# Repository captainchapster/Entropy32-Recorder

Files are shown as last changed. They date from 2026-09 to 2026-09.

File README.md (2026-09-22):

# Entropy32 Recorder

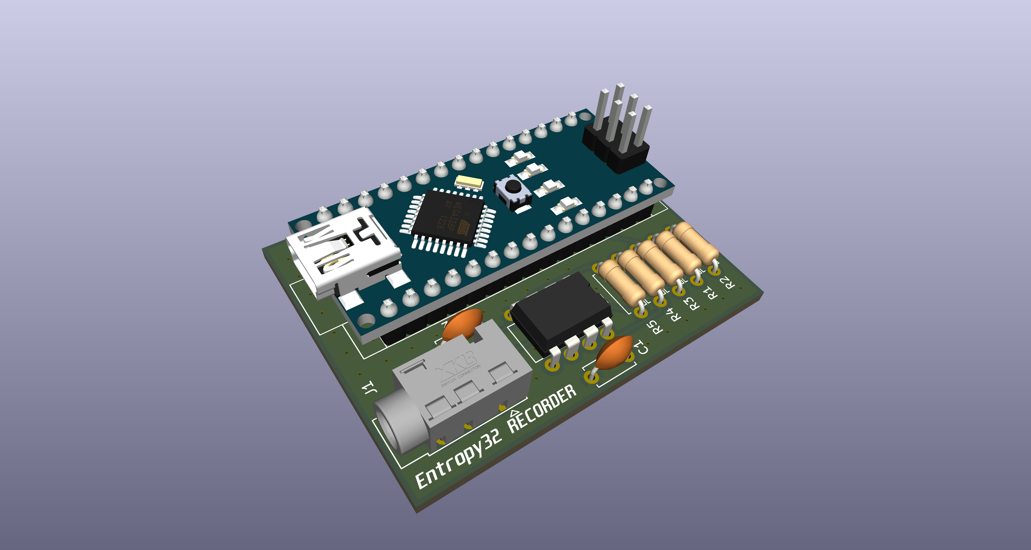
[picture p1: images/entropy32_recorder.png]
Assembled PCB


Firmware, hardware, and tooling for the Entropy32 Recorder — a standalone
Geiger-counter-based board, built around an ATmega328P (Arduino Nano form
factor), for recording raw entropy source data.

This is a **separate board from Entropy32 / Entropy32 Plus**, not a mode or
alternate firmware of it. It does not generate seeds or any conditioned
output. Its only job is to capture raw, unconditioned edge timing data from
the entropy source (Geiger tube + LM393 comparator) so it can be run through
statistical test suites (e.g. NIST STS) to validate the quality of the
entropy source itself, before that source is trusted for use in Entropy32
Plus's seed generation.

## Repository layout

- **`entropy32_evidence_protocol.md`** — the SP 800-90B reproducible
  evidence protocol these tools implement: capture requirements, the
  raw/derived evidence package layout, exact firmware reconstruction
  semantics, and the pinned NIST toolchain invocation.
- **`entropy32_recorder.ino`** — the recorder's firmware. It timestamps
  every rising edge on D2 (post-LM393 comparator output) and streams
  `edge_index,timestamp_us` CSV rows over serial. It does no filtering,
  interval pairing, or SHA-256 conditioning by design — it's for capturing
  raw edge timing data only, unmodified, for statistical testing.
- **`tools/capture_serial_to_csv.py`** — reads the serial stream produced by
  the sketch above and writes it to a CSV file matching the evidence
  protocol's `raw/raw_edges.csv` shape (`edge_index`, `raw_timer_ticks`,
  `monotonic_timestamp_us`). `raw_timer_ticks` is the board's `micros()`
  reading exactly as received (wraps every ~71.58 min);
  `monotonic_timestamp_us` is that value unwrapped into an ever-increasing
  64-bit microsecond count, reconstructed on the host (via
  `tools/edge_timing.py`) so the firmware/ISR stays minimal. Every row is
  flushed and fsynced to disk as soon as it's written — negligible cost at
  this source's event rate, and each edge is an irreplaceable physical
  event, so nothing is ever buffered short of an actual power loss. One
  capture is one continuous, uninterrupted run from edge 0 — per the
  evidence protocol, there is no resume; the tool refuses to run at all
  if `--out` already has data, and an interrupted capture must be
  restarted under a new `--out` rather than continued. On a fully
  complete run, also writes a `capture_status.json` sibling (e.g.
  `raw_edges.status.json`) recording edge count, start/end UTC
  timestamps, and the zero overrun/drop counts implied by reaching that
  point at all — this feeds `tools/package_evidence.py` and the
  protocol's `capture_status.json` (§4). Requires `pyserial`.
- **`tools/edge_timing.py`** — the timer-wrap-unwrapping math used by the
  capture tool, in its own module mainly so it can be tested in isolation.
- **`tools/check_edges.py`** — pre-flight sanity check for a captured CSV:
  confirms `edge_index`/`monotonic_timestamp_us` are well-formed, and
  compares the inter-arrival distribution against a Poisson expectation to
  flag comparator bounce/chatter. Run this before feeding a capture into
  NIST STS / SP 800-90B tooling:
  `python tools/check_edges.py tools/raw_edges.csv`.
- **`tools/derive_evidence.py`** — reconstructs Entropy32's actual
  bit-extraction (200us reject filter, non-overlapping interval pairing,
  second-longer=1/second-shorter=0, ties discarded) per
  `entropy32_evidence_protocol.md` §5,
  producing the protocol's `derived/` package — `all_intervals_us.csv`,
  `firmware_accepted_intervals_us.csv`, `comparison_bits.bin`,
  `derivation_report.json`.
  `python tools/derive_evidence.py tools/raw_edges.csv --out-dir tools/derived --source-dir ../entropy32_plus`.
  `comparison_bits.bin` is ready for `ea_non_iid -i -v comparison_bits.bin 1`
  (bits_per_symbol=1, per the protocol's §8 — not a byte-per-symbol
  truncation). `--source-dir` (optional but recommended) points at a local
  checkout of the firmware these constants are claimed to match, and
  auto-fills `derivation_report.json`'s `source_repo`/`source_commit`/
  `entropy32_firmware_blob_sha` from its git metadata and `.ino` hash —
  left `"unknown"` rather than guessed if omitted.
- **`tools/package_evidence.py`** — assembles the protocol's immutable
  evidence directory (§4) from a capture, a `derive_evidence.py` run, and
  a separately-run `ea_non_iid` pass: copies `raw/` and `derived/` in,
  records the exact NIST command/toolchain/exit status under `nist/`,
  writes `capture_status.json` and a `manifest.json` (fields it can't
  know — hardware, physical source, environment — are left `null` and
  listed on stdout for manual completion), and computes a `SHA256SUMS`
  covering every file in the package.
- **`KiCad/`** — PCB design (schematic, layout, 3D models, and
  fabrication/production outputs for the Entropy32 Recorder board).

## Hardware

Assembled PCB

The board pairs a Geiger tube's LM393 comparator output with an ATmega328P
(D2, using the board's existing pull-down for bias). Design files are in
[`KiCad/`](KiCad/), including BOM, designators, netlist, and pick-and-place
files under `KiCad/production/`.

## Usage

All commands below assume you're in the repo root (`entropy32_recorder/`)
and refer to files under `tools/` explicitly — that avoids the most common
mistake, running a later step from the wrong directory against a bare
filename that only exists one level down.

1. Flash `entropy32_recorder.ino` to the board.
2. Install the one Python dependency, then run the capture tool:

   ```
   pip install pyserial
   python tools/capture_serial_to_csv.py --port COM5 --count 2000 --out tools/raw_edges.csv
   ```

   (`--port` is a COM port like `COM5` on Windows, or a device path like
   `/dev/ttyUSB0` on Linux.) This writes `tools/raw_edges.csv` and, once
   the run completes fully, a `tools/raw_edges.status.json` sibling.
3. If the board reports `OVERRUN_DETECTED`, or the capture stops for any
   other reason (crash, USB drop, closing the terminal), that run is
   invalid per the evidence protocol — one capture is one continuous,
   uninterrupted run from edge 0. Start over under a new `--out`; there
   is no resume. Don't reuse `tools/raw_edges.csv` as the target for a new
   capture once an earlier one has already been packaged (step 7) — that
   overwrites the file the earlier package's hashes were computed from.
4. Sanity-check the result before running heavier statistical tests:

   ```
   python tools/check_edges.py tools/raw_edges.csv
   ```

5. Reconstruct Entropy32's actual bit stream:

   ```
   python tools/derive_evidence.py tools/raw_edges.csv --out-dir tools/derived --source-dir ../entropy32_plus
   ```

   This writes `tools/derived/comparison_bits.bin` (and the other
   `derived/` files) ready for the NIST tool below.
6. Run the NIST non-IID test suite against `comparison_bits.bin`.

   `ea_non_iid` is a Linux build — on Windows you'll need
   [WSL](https://learn.microsoft.com/en-us/windows/wsl/install)
   (`wsl --install`, one-time). Build it once, from inside WSL (or any
   Linux/macOS shell):

   ```bash
   sudo apt update && sudo apt install -y build-essential libbz2-dev
   git clone https://github.com/usnistgov/SP800-90B_EntropyAssessment.git
   cd SP800-90B_EntropyAssessment
   git checkout 68ed165fd7a3eeef26b87a546ba23f338e82a3f3  # pinned v1.1.8, see protocol §8
   make
   cd selftest && ./selftest && cd ..
   make non_iid
   ```

   The binaries land in `cpp/`, not the repo root — run `ea_non_iid` from
   there. From WSL, your Windows checkout is under `/mnt/<drive letter>/...`
   (e.g. `/mnt/d/Programming/entropy32_recorder`). Run it and save its
   stdout/stderr/exit status verbatim — the next step needs all three:

   ```bash
   cd SP800-90B_EntropyAssessment/cpp
   REPO=/mnt/d/Programming/entropy32_recorder
   ./ea_non_iid -i -v "$REPO/tools/derived/comparison_bits.bin" 1 \
     > "$REPO/tools/nist_stdout.txt" 2> "$REPO/tools/nist_stderr.txt"
   echo $? > "$REPO/tools/nist_exit_status.txt"
   g++ --version | head -1   # note this down for --nist-compiler-version below
   ```

7. Assemble the immutable evidence package:

   ```
   python tools/package_evidence.py \
     --raw tools/raw_edges.csv --derived-dir tools/derived --capture-id <your-id> \
     --nist-command "./ea_non_iid -i -v comparison_bits.bin 1" \
     --nist-stdout tools/nist_stdout.txt --nist-stderr tools/nist_stderr.txt \
     --nist-exit-status 0 --nist-compiler-version "<g++ --version output from step 6>"
   ```

   `--capture-status` doesn't need to be passed explicitly — it's
   auto-detected from `tools/raw_edges.status.json`. This writes
   `entropy32_sp80090b_<your-id>/` in the repo root; that directory,
   not the loose `tools/raw_edges.csv` / `tools/derived/` / `tools/nist_*`
   files that fed it, is what should get committed as the evidence record.

   Fill in whichever `manifest.json` fields it lists as left `null`
   (hardware revision, physical source, environment) by hand — see
   `entropy32_evidence_protocol.md` for what the full package and
   restart testing require beyond this.

## Known limitations / best practices for a full campaign

- **Sample size**: a few thousand edges (a few hours at typical background
  rates) is only enough for a pipeline smoke test. SP 800-90B-style
  min-entropy estimation wants **>= 1,000,000 samples** before the result
  is meaningful — plan campaign length accordingly (at the ~16 CPM
  background rate seen in the pilot run, 1M edges is roughly 6 weeks of
  continuous capture).
- **Timestamp resolution**: `micros()` on the ATmega328P (16MHz, Timer0
  prescaler 64) only increments in steps of 4us. That's negligible at the
  observed ~3.7s mean inter-arrival time (1 part in ~10^6), so it isn't a
  concern at current event rates. If a future hardware revision moves the
  comparator output to the Timer1 input-capture pin (`ICP1` / D8 on a
  Nano) instead of D2, the ISR could latch `TCNT1` directly for
  microsecond-or-better hardware-timestamped edges with no software ISR
  jitter — worth considering for a higher-throughput source, but out of
  scope for the current board (D2 is fixed on the fabricated PCB).
- **Comparator bounce**: `check_edges.py` compares the inter-arrival
  distribution against the Poisson process a radioactive source should
  produce; a pileup of anomalously short gaps indicates LM393 output
  chatter rather than genuine independent events. No bounce was observed
  in the pilot 2000-edge run.

## License

- Firmware and software (`entropy32_recorder.ino`, `tools/`): [MIT](LICENSE)
- Hardware (`KiCad/`): [CERN-OHL-S v2](LICENSE-HARDWARE)

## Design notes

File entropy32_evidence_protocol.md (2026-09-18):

# Entropy32 Plus · SP 800-90B Reproducible Evidence Protocol v0.1

**Status:** evidence protocol, not certification.
**Drafted by:** Cosmographer / BHRIGU

This protocol is written to apply to any build of the Entropy32 Plus
firmware. Pin the specific repository, commit, and firmware blob hash you
are evaluating in your own manifest (§10) rather than in this document.

Entropy32 currently measures Geiger pulse inter-arrival time using D2, rejects intervals below `200 µs`, consumes accepted intervals in non-overlapping pairs, discards ties, emits `1` when the second interval is longer and `0` when shorter, and only then runs health tests / fills the 512-bit pool. Entropy32 Plus's own README correctly notes that runtime health tests are not full entropy validation, and that a long raw inter-arrival dataset still needs SP 800-90B non-IID assessment.

## 1. Evidence boundary

The acquisition point is:

```text
PHYSICAL SOURCE
    ↓
Geiger detector pulse
    ↓
LM393 comparator
    ↓
D2 rising edge
    ↓
[CAPTURE HERE]
    ↓
200 µs filter
    ↓
non-overlapping interval pairing
    ↓
comparison bit
    ↓
RCT / APT
    ↓
512-bit pool
    ↓
SHA-256
```

**Every D2 rising edge is recorded before any filtering, pairing, health test, pool logic or SHA-256.**

For this protocol:

```text
RAW EVIDENCE
= direct D2 edge observations

DERIVED EVIDENCE
= intervals, accepted intervals,
  comparison bits and statistical results
  reconstructed from those observations
```

One terminology note matters: SP 800-90B calls the digitized output of the defined noise source its “raw data.” Here we deliberately preserve an even earlier observational authority—the D2 edge timestamps—so that different candidate digitized-sample definitions can be reconstructed without recollecting the experiment. NIST explicitly expects access to digitized noise-source data for validation and external testing. ([NIST Publications](https://nvlpubs.nist.gov/nistpubs/specialpublications/nist.sp.800-90b.pdf "Recommendation for the Entropy Sources Used for Random Bit Generation"))

---

## 2. Recorder requirements

The recorder must timestamp edges itself. **PC receive time must never be used as the entropy timestamp.**

Required properties:

| Property | Requirement |
| --- | --- |
| Input | rising edge on the same post-LM393 signal used as Entropy32 D2 |
| Timestamp source | free-running hardware timer |
| Resolution | **≤ 1 µs preferred; never worse than the Entropy32 timing resolution** |
| Clock | oscillator source and nominal frequency recorded |
| Monotonicity | recorder maintains an unambiguous monotonically increasing timestamp across timer wraps |
| Edge index | 64-bit monotonically increasing counter, incremented for every captured edge |
| ISR | only timestamp/store; no printing, formatting or blocking I/O |
| Buffer | ring/DMA buffer; overflow counter mandatory |
| Transport | foreground transfer to PC |
| Drop detection | sequence gaps or buffer overrun invalidate the capture |
| Capture end | sample-count based, not time based |

Current Entropy32 uses `micros()` on a 16 MHz ATmega328P. The standard Arduino AVR implementation derives `micros()` from Timer0 with a 64-clock prescaler; at 16 MHz its returned values advance in 4 µs units. ([GitHub](https://github.com/arduino/ArduinoCore-avr/blob/master/cores/arduino/wiring.c?utm_source=chatgpt.com "ArduinoCore-avr/cores/arduino/wiring.c at master · arduino/ArduinoCore-avr · GitHub"))

Therefore the recorder should preserve higher-resolution physical timestamps but also record enough timing/toolchain metadata to reproduce the deployed Entropy32 timing semantics. The manifest must state the actual Arduino AVR core/toolchain used by the device; the firmware repository alone does not pin that dependency.

### Overflow handling

Do **not** allow a wrapped 32-bit timestamp to become ambiguous.

Recommended stored edge record:

```text
edge_index
raw_timer_ticks
monotonic_timestamp_us
```

`monotonic_timestamp_us` must remain increasing for the whole run. If the underlying hardware timer wraps, the recorder must extend it before writing the evidence record.

### Dropped-event criterion

A run is valid only if:

```text
first_edge_index = 0
every next edge_index = previous + 1
buffer_overrun_count = 0
transport_drop_count = 0
records_received = recorder_records_sent
```

Any violation:

```text
CAPTURE_INVALID
```

Do not patch the file or interpolate missing events.

---

## 3. Minimum acquisition length

NIST requires at least **1,000,000 sequential noise-source samples** for the sequential dataset; if multiple consecutive segments are concatenated, each segment must contain at least 1,000 samples. ([NIST Publications](https://nvlpubs.nist.gov/nistpubs/specialpublications/nist.sp.800-90b.pdf "Recommendation for the Entropy Sources Used for Random Bit Generation"))

For this evidence package, use a stricter practical stop gate:

```text
UNFILTERED_INTERARRIVAL_SAMPLES >= 1,000,000

AND

COMPARISON_BITS >= 1,000,000
```

That ensures there is enough evidence to inspect the physical timing observations **and** a full one-million-sample binary dataset corresponding to the stream actually entering Entropy32's health-test/pool path.

Because each comparison bit consumes two accepted intervals and ties emit no bit, the recorder must continue until the second condition is reached rather than assuming a fixed number of pulses.

The capture duration therefore depends on observed count rate. It is not defined by isotope, CPM estimate or wall-clock duration.

---

## 4. Immutable package

The final evidence directory is:

```text
entropy32_sp80090b_<capture-id>/

  manifest.json
  capture_status.json
  SHA256SUMS

  raw/
    raw_edges.csv

  derived/
    all_intervals_us.csv
    firmware_accepted_intervals_us.csv
    comparison_bits.bin
    derivation_report.json

  nist/
    TOOLCHAIN.txt
    comparison_non_iid.command.txt
    comparison_non_iid.stdout.txt
    comparison_non_iid.stderr.txt
```

### `raw/raw_edges.csv`

One record per physical D2 rising edge:

```text
edge_index,raw_timer_ticks,monotonic_timestamp_us
0,...
1,...
2,...
...
```

This file is the primary observational authority.

Once closed:

1. do not edit, sort, normalize or re-export it;
2. calculate SHA-256 immediately;
3. include that digest in `SHA256SUMS` and `manifest.json`.

---

## 5. Exact firmware reconstruction

Starting from `raw_edges.csv`, first derive every consecutive physical inter-arrival value:

```text
all_interval[n] =
edge_timestamp[n] - edge_timestamp[n-1]
```

Do **not** apply modulo, low-byte extraction, bucketing or truncation.

Then reconstruct current Entropy32 semantics.

Current firmware does something subtle and important: an interval below `200 µs` is rejected **without updating** **`lastPulseMicros`**. The next interval is therefore measured from the last accepted edge, not from the rejected edge.

Equivalent reconstruction:

```text
last_accepted_edge = NONE
have_first_interval = false

for each raw D2 edge in original order:

    if first edge:
        last_accepted_edge = edge
        continue

    interval =
        edge.time - last_accepted_edge.time

    if interval < 200 µs:
        reject
        DO NOT update last_accepted_edge
        continue

    accepted interval

    if have_first_interval == false:
        first_interval = interval
        have_first_interval = true

    else:
        second_interval = interval

        if second_interval > first_interval:
            emit comparison bit 1

        if second_interval < first_interval:
            emit comparison bit 0

        if second_interval == first_interval:
            emit no bit

        have_first_interval = false

    last_accepted_edge = edge
```

That is the current `geigerISR()` behavior.

### `derivation_report.json`

At minimum:

```json
{
  "source_repo": "your-org/your-repo",
  "source_commit": "<commit-sha>",
  "entropy32_firmware_blob_sha": "<firmware-blob-sha>",
  "min_interval_us": 200,
  "pairing": "NON_OVERLAPPING",
  "tie_rule": "DISCARD_PAIR",
  "bit_rule": "SECOND_LONGER=1;SECOND_SHORTER=0",
  "raw_edges": 0,
  "unfiltered_intervals": 0,
  "short_interval_rejections": 0,
  "accepted_intervals": 0,
  "complete_pairs": 0,
  "ties": 0,
  "comparison_zeroes": 0,
  "comparison_ones": 0,
  "comparison_bits": 0
}
```

The counts must reconcile exactly.

---

## 6. RAW and DERIVED must remain separate

Do not call `comparison_bits.bin` the original physical capture.

```text
RAW AUTHORITY
raw_edges.csv

        ↓ deterministic reconstruction

DERIVED
all_intervals_us.csv

        ↓ exact current 200 µs semantics

DERIVED
firmware_accepted_intervals_us.csv

        ↓ non-overlapping comparison

DERIVED
comparison_bits.bin
```

This separation is important because SP 800-90B's entropy assessment depends on what is explicitly defined as the digitized noise-source sample. NIST defines raw data as the output of the digitized noise source. ([NIST Publications](https://nvlpubs.nist.gov/nistpubs/specialpublications/nist.sp.800-90b.pdf "Recommendation for the Entropy Sources Used for Random Bit Generation"))

The protocol therefore preserves enough earlier evidence to revisit that boundary later without repeating the physical experiment.

---

## 7. Raw interval alphabet issue

Do **not** silently convert interval values using:

```text
interval % 256
low_byte(interval)
truncate_to_uint8
arbitrary bins
```

Current Entropy32 source does none of those things.

SP 800-90B requires an alphabet larger than 256 symbols to be reduced to at most 256 before the specified entropy estimators are applied, and Section 6.4 requires the reduction to be justified/documented. ([NIST Publications](https://nvlpubs.nist.gov/nistpubs/specialpublications/nist.sp.800-90b.pdf "Recommendation for the Entropy Sources Used for Random Bit Generation")) NIST even discusses timing samples as an example where selected lower-order bits might be reasonable—but that decision must follow a model/ranking argument, not be assumed in advance. ([NIST Publications](https://nvlpubs.nist.gov/nistpubs/specialpublications/nist.sp.800-90b.pdf "Recommendation for the Entropy Sources Used for Random Bit Generation"))

Therefore:

```text
FULL INTERVAL DATA
= preserve unchanged

RAW-SOURCE SYMBOL REDUCTION
= separate documented analysis decision
```

No reduction rule is part of v0.1.

---

## 8. Ready NIST non-IID binary package

`comparison_bits.bin` is immediately compatible with the NIST tool because it has exactly one binary symbol per byte:

```text
0x00
0x01
0x00
...
```

Pin the current official NIST toolchain:

```text
repository:
usnistgov/SP800-90B_EntropyAssessment

tag:
v1.1.8

commit:
68ed165fd7a3eeef26b87a546ba23f338e82a3f3
```

The tag currently resolves to that exact commit.

Build and self-test:

```bash
make
cd selftest
./selftest
cd ..
make non_iid
```

Then:

```bash
./ea_non_iid \
  -i \
  -v \
  comparison_bits.bin \
  1
```

The official tool documents `-i` as unconditioned input, accepts one symbol per byte, and uses `bits_per_symbol=1` for this binary package.

Save verbatim:

```text
command line
tool git commit
compiler/version
stdout
stderr
exit status
SHA256(comparison_bits.bin)
```

For non-IID data, SP 800-90B requires all ten estimators—MCV, Collision, Markov, Compression, t-Tuple, LRS, MultiMCW, Lag, MultiMMC and LZ78Y—and uses the minimum result. ([NIST Publications](https://nvlpubs.nist.gov/nistpubs/specialpublications/nist.sp.800-90b.pdf "Recommendation for the Entropy Sources Used for Random Bit Generation"))

Label the result:

```text
NON_IID_ESTIMATE_OF_DERIVED_COMPARISON_STREAM
```

Do **not** label it:

```text
FULL_ENTROPY32_VALIDATION
```

until the complete source boundary, raw-source estimate, restart testing and remaining SP 800-90B requirements are addressed.

---

## 9. Restart data is a separate required campaign

This first long sequential capture is **not** the restart test.

SP 800-90B requires:

```text
1000 restarts
×
1000 consecutive noise-source samples per restart
```

collected as soon as the source is ready for real-world output under the defined restart procedure. ([NIST Publications](https://nvlpubs.nist.gov/nistpubs/specialpublications/nist.sp.800-90b.pdf "Recommendation for the Entropy Sources Used for Random Bit Generation"))

The standard then compares row/column restart estimates to the initial estimate; the final assessment uses the minimum when the restart criteria pass. ([NIST Publications](https://nvlpubs.nist.gov/nistpubs/specialpublications/nist.sp.800-90b.pdf "Recommendation for the Entropy Sources Used for Random Bit Generation"))

Therefore restart collection should become a **second protocol** after the sequential acquisition boundary has been agreed.

---

## 10. Minimum manifest

`manifest.json` should contain at least:

```text
protocol_version
capture_id
capture_start_utc
capture_end_utc

repository
repository_commit
entropy32_firmware_blob_sha

hardware_revision
board_identifier
capture_point
edge_polarity

geiger_counter_model
physical_source_type
source_identifier_if_any
source_geometry
source_distance
shielding_or_enclosure

recorder_hardware
recorder_firmware_hash
compiler_version
arduino_core_or_runtime_version

clock_source
nominal_clock_hz
measured_clock_hz_if_known
timestamp_resolution
timer_width
overflow_extension_method

MIN_INTERVAL_US=200
RAW_POOL_BITS=512
pairing=NON_OVERLAPPING
tie_rule=DISCARD

ambient_temperature_if_available
supply_voltage_if_available
other_environment_notes

raw_edge_count
capture_status
buffer_overruns
transport_drops

nist_tool_repository
nist_tool_version
nist_tool_commit

file_sha256
```

Unknown values are written as `null` or `unknown`, not guessed.

---

## 11. Smallest recorder architecture

```text
                     ┌─────────────────────────┐
PHYSICAL SOURCE ───► │ Geiger detector         │
                     └───────────┬─────────────┘
                                 │ pulse
                                 ▼
                     ┌─────────────────────────┐
                     │ existing LM393 stage    │
                     └───────────┬─────────────┘
                                 │
                         post-LM393 D2 node
                                 │
                    ┌────────────┴─────────────┐
                    │                          │
                    ▼                          ▼
          Entropy32 Plus D2          validation recorder
                                     high-impedance input
                                             │
                                             ▼
                                   hardware edge timestamp
                                             │
                                      ring buffer
                                             │
                                             ▼
                                      USB → PC logger
```

**Preferred:** tap the existing post-LM393 signal with a high-impedance recorder input. That means the recorder observes the same electrical events as Entropy32 rather than creating a second analog entropy path.

The recorder needs no OLED, BIP39, SHA-256, entropy health logic or wallet functionality. Its only job is:

```text
EDGE
→ TIMESTAMP
→ SEQUENCE NUMBER
→ LOSS-DETECTABLE BUFFER
→ PC
```

No printing or USB work occurs inside the edge ISR.

A completely separate standalone recorder can mirror the same LM393 front end if desired, but that is secondary; the direct D2 tap is the smaller and stronger first evidence architecture.

---

## 12. Am-241

Am-241 is **not** a protocol requirement.

It is one possible physical source and should appear only in metadata:

```text
physical_source_type = "Am-241"
```

if that is what was actually used.

The protocol works equally with another source or background radiation. The isotope name, source activity or CPM alone does **not** establish min-entropy.

If Am-241 is used, record its available identifying/activity/geometry information and use it under applicable safety and legal requirements. The acquisition and statistical rules remain unchanged.

---

## 13. What this protocol proves

A successful run can establish:

- exactly what D2 edges were observed;
- that the dataset has no detected recorder drops;
- exact provenance to a named firmware commit and blob hash;
- reproducible reconstruction of the current 200 µs filter and non-overlapping pairing;
- the exact binary sequence entering the comparison-bit health/pool path;
- reproducible non-IID estimator results from a pinned NIST toolchain.

It **does not** by itself establish:

- NIST certification or formal validation;
- that radioactive decay as a category guarantees a particular entropy rate;
- that one physical source/device/environment represents all others;
- an IID claim;
- restart-test compliance;
- correctness of every Entropy32 hardware/software component;
- security of a resulting Bitcoin seed end-to-end;
- adequacy of health-test thresholds unless they are later tied to the assessed entropy.

NIST distinguishes entropy assessment from formal validation; formal validation involves accredited laboratory testing and program review. ([NIST Publications](https://nvlpubs.nist.gov/nistpubs/specialpublications/nist.sp.800-90b.pdf "Recommendation for the Entropy Sources Used for Random Bit Generation"))

---

## 14. Execution checklist

1. Freeze the firmware repository commit being evaluated.
2. Record the exact `entropy32_plus.ino` blob hash.
3. Tap the **post-LM393 D2 rising-edge signal**.
4. Confirm recorder timestamp resolution ≤1 µs and document its clock.
5. Verify timestamp wrap extension is monotonic.
6. Verify ISR only timestamps/buffers events.
7. Verify sequence numbering and zero-overrun counters.
8. Perform a short pilot capture first.
9. Confirm every edge index is consecutive and `drops=0`.
10. Hash the raw capture immediately.
11. Run offline reconstruction with exact `MIN_INTERVAL_US=200` semantics.
12. Confirm rejected short intervals do **not** advance `lastPulseMicros`.
13. Pair accepted intervals non-overlapping.
14. Discard ties; emit `1` for second-longer and `0` for second-shorter.
15. Confirm all derivation counts reconcile.
16. Run the long capture until both ≥1M unfiltered intervals and ≥1M comparison bits exist.
17. Freeze and hash raw + derived files.
18. Pin NIST `SP800-90B_EntropyAssessment` v1.1.8 / `68ed165f…`.
19. Run NIST self-tests.
20. Run `ea_non_iid -i -v comparison_bits.bin 1`.
21. Preserve command, tool version, stdout/stderr and hashes.
22. Do **not** invent an interval-to-byte reduction rule for the full interval dataset.
23. Review the raw interval distribution before defining any Section 6.4 reduction.
24. Treat restart testing as the subsequent campaign, not as satisfied by this run.
25. Do not call the result certification or full SP 800-90B validation.

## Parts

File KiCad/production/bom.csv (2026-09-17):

Designator | Footprint | Quantity | Value | LCSC Part #
A1 | Arduino_Nano | 1 | Arduino_Nano_v2.x
C1 | C_Disc_D5.0mm_W2.5mm_P5.00mm | 1 | 100nF
C2 | C_Disc_D5.0mm_W2.5mm_P5.00mm | 1 | 100pF
J1 | Jack_3.5mm_PJ320E_Horizontal | 1 | AudioJack2
R1, R4 | R_Axial_DIN0207_L6.3mm_D2.5mm_P7.62mm_Horizontal | 2 | 10k
R2, R5 | R_Axial_DIN0207_L6.3mm_D2.5mm_P7.62mm_Horizontal | 2 | 1k
R3 | R_Axial_DIN0207_L6.3mm_D2.5mm_P7.62mm_Horizontal | 1 | 100k
U1 | DIP-8_W7.62mm | 1 | LM393

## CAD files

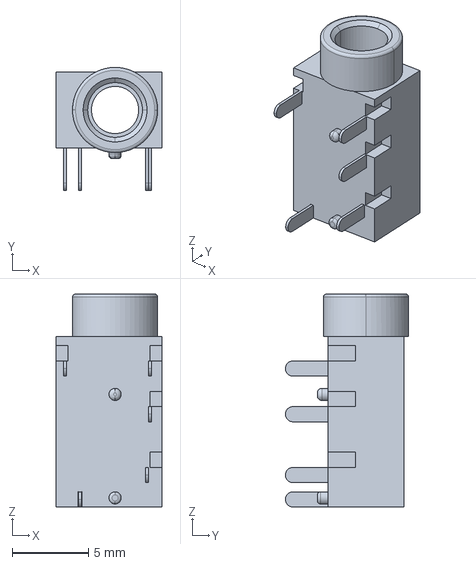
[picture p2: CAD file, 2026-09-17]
KiCad/3d_models/189198069-19-pj-320e/pj-320e.stp
7.00 x 8.10 x 14.0 mm

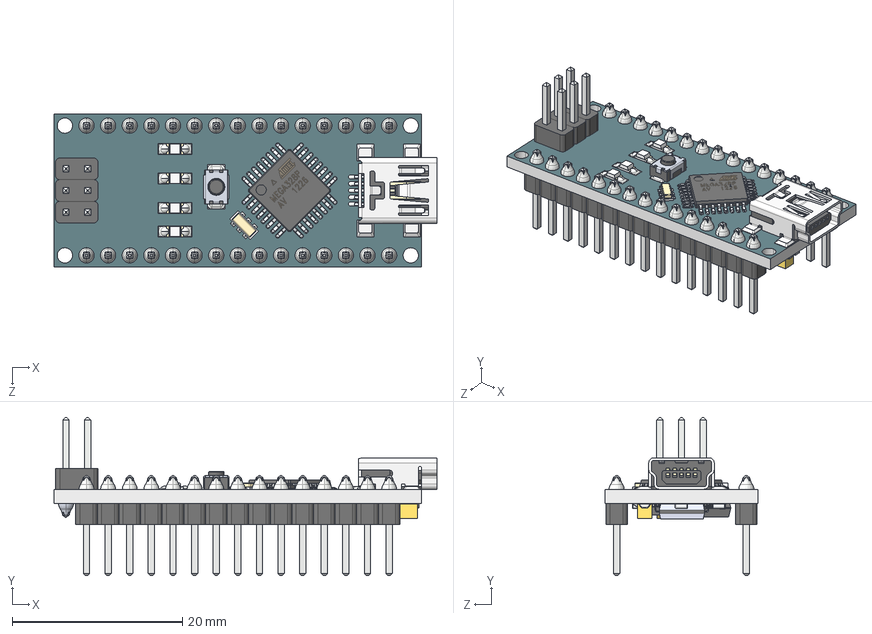
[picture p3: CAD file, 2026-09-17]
KiCad/3d_models/arduino_nano/arduino-nano.step
45.0 x 18.6 x 18.0 mm
nano-board
2pin_header__02 x 3
15pin_header__ x 2
atmega328
ftdi FT232rl
smt_resistor222 x 5
led x 4
16mhz crystal - measured
MINIUSBSHELL
MINIUSBCORE
MINI USB CONTACT x 5
cap106C x 2
reset core
reset shell
nano - reg
NANO DIODE
189 RESISTOR PACK
102 RESISTOR PACK

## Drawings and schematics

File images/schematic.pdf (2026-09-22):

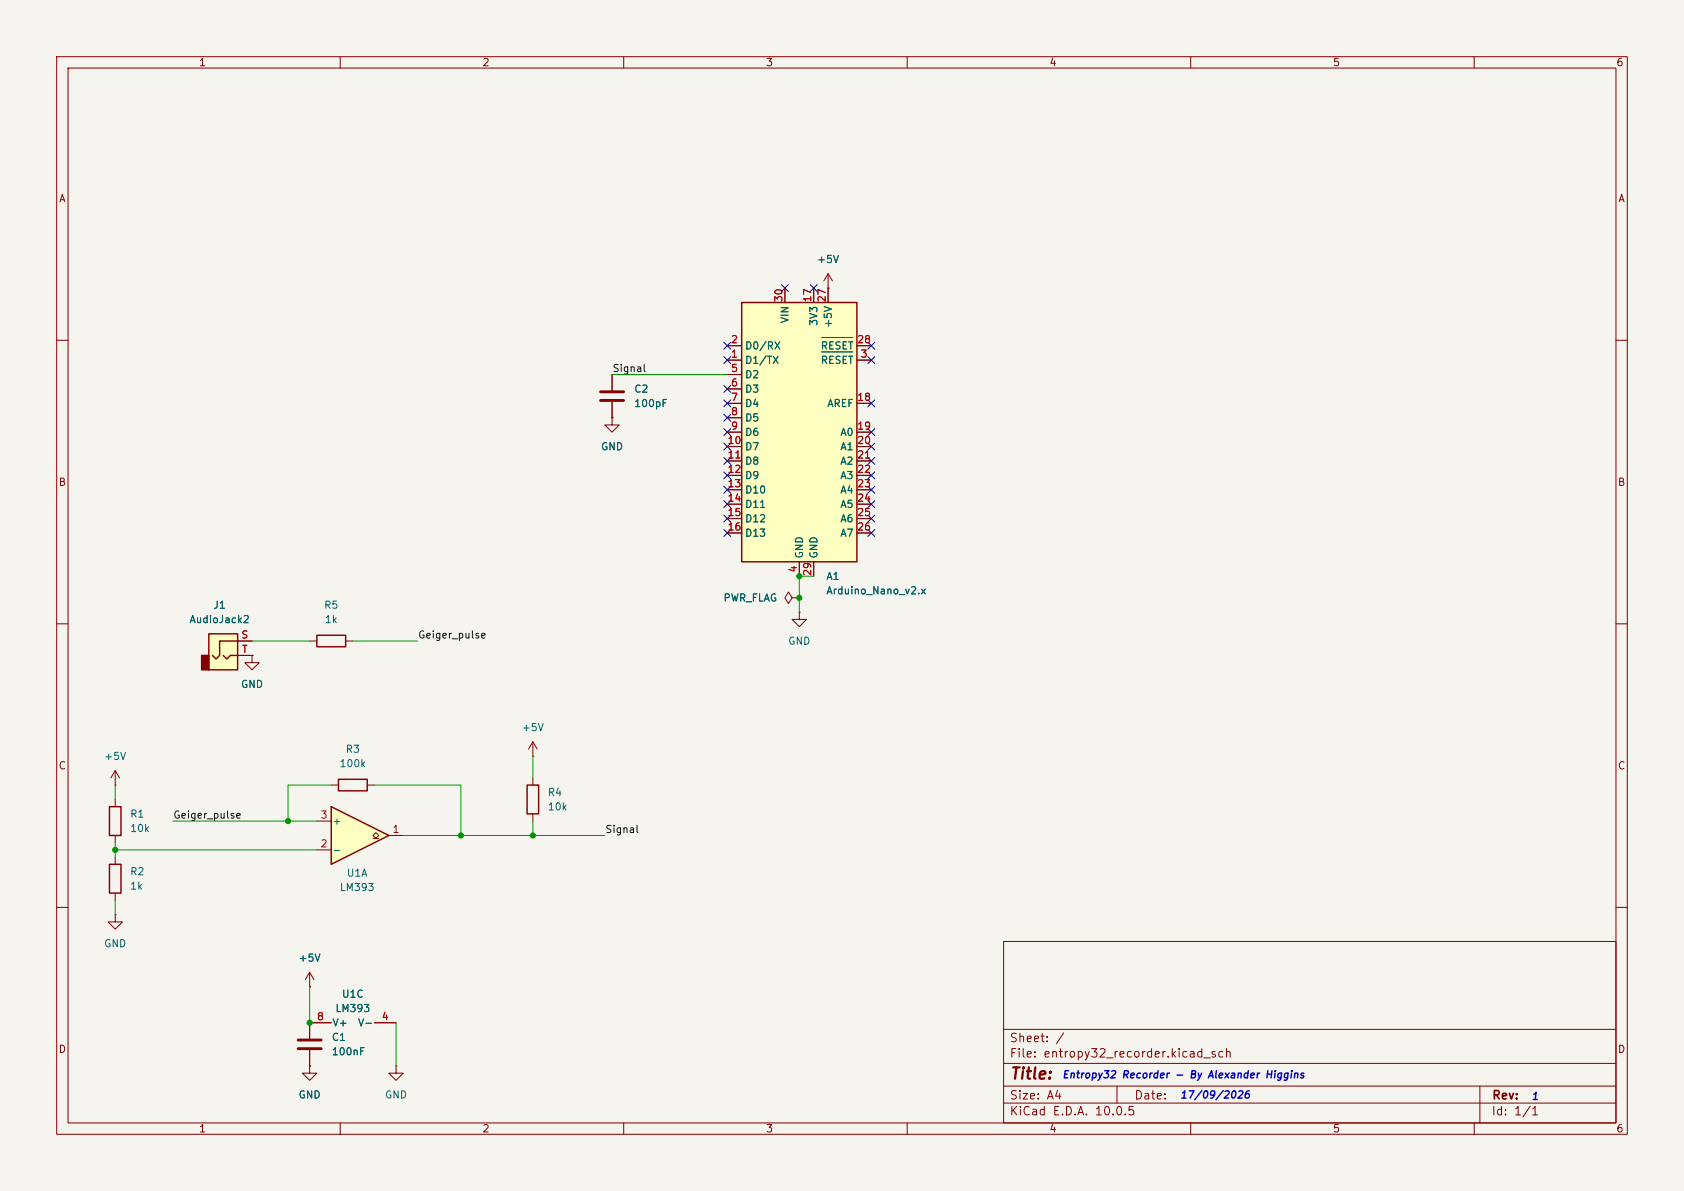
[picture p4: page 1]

Entropy32 Recorder - By Alexander Higgins

Size: A4 | Rev:
KiCad E.D.A. 10.0.5 | Id: 1/1

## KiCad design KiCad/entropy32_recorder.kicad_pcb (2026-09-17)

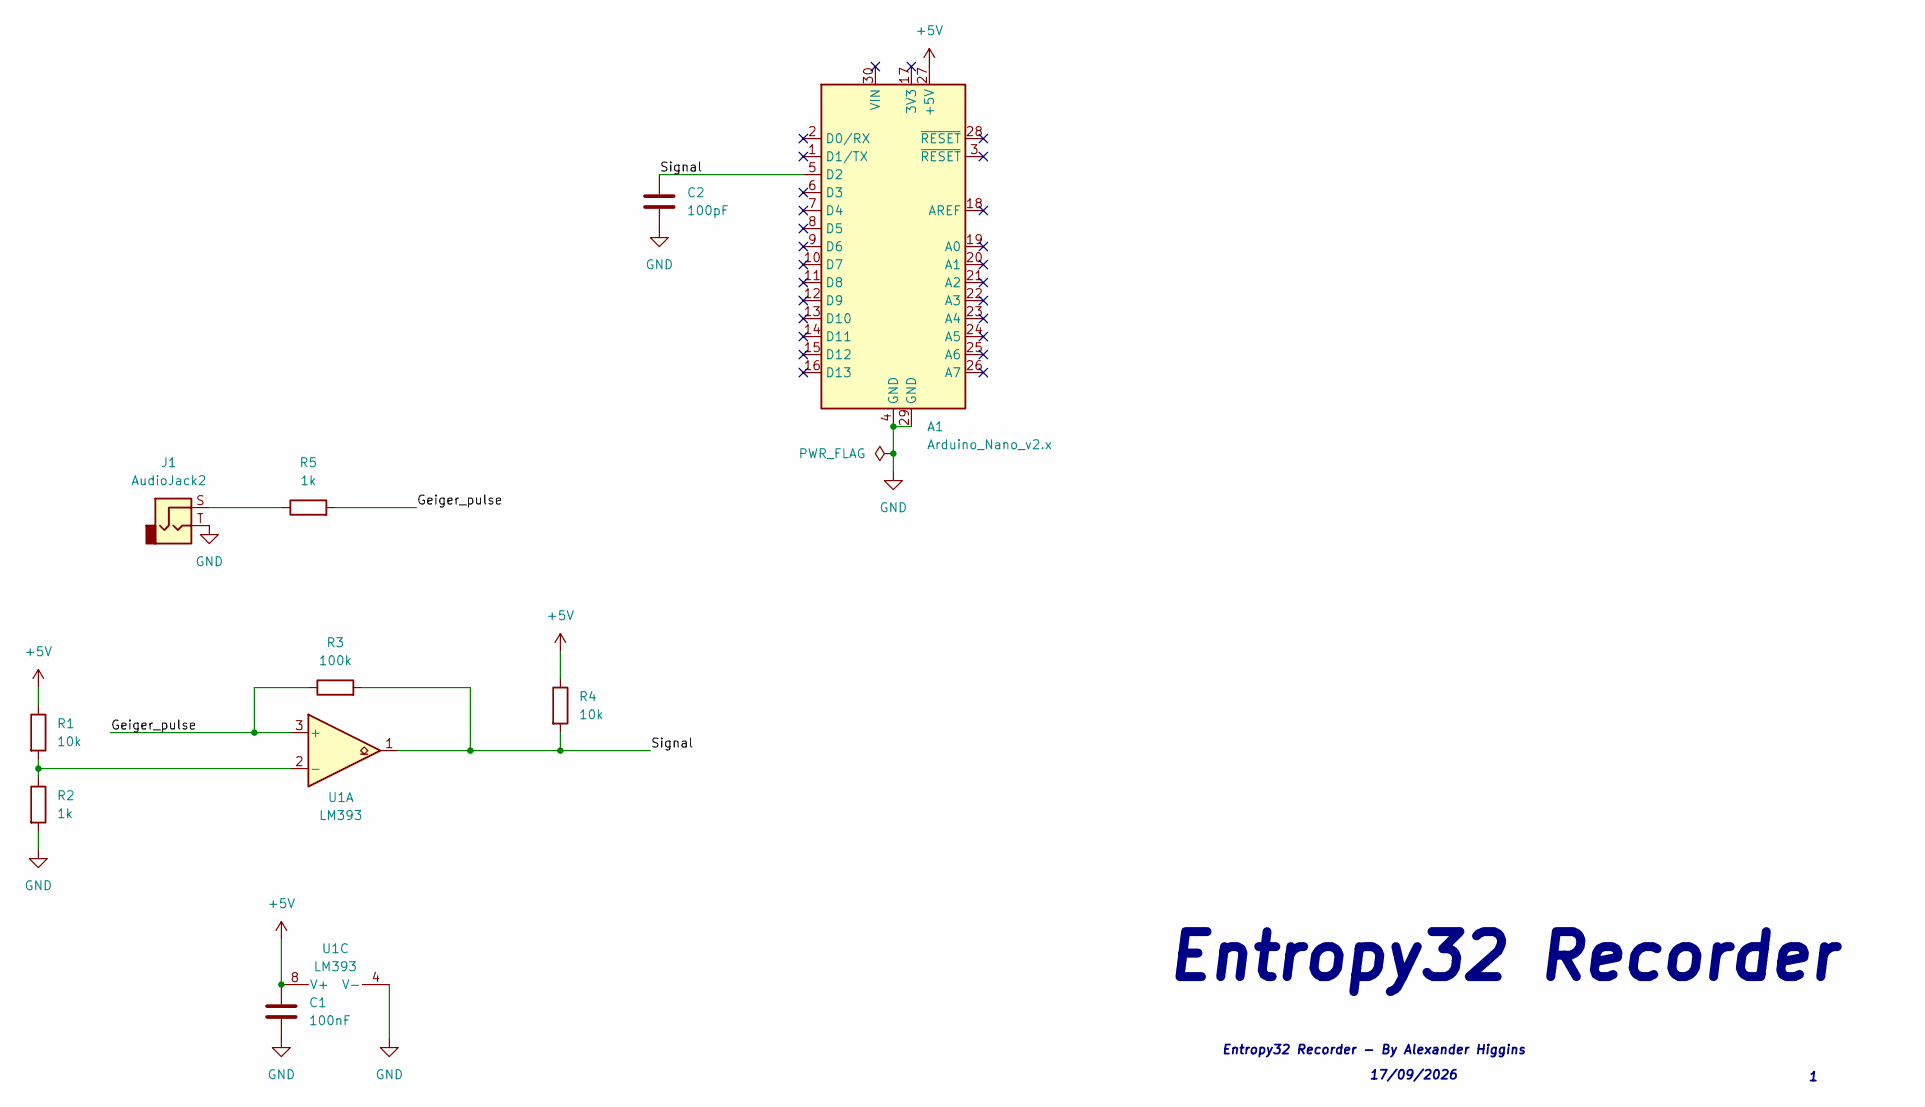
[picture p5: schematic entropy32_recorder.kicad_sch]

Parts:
A1: Arduino_Nano_v2.x; Arduino_Nano
C1: 100nF; C_Disc_D5.0mm_W2.5mm_P5.00mm
C2: 100pF; C_Disc_D5.0mm_W2.5mm_P5.00mm
J1: AudioJack2; Jack_3.5mm_PJ320E_Horizontal
R1, R4: 10k; R_Axial_DIN0207_L6.3mm_D2.5mm_P7.62mm_Horizontal
R2, R5: 1k; R_Axial_DIN0207_L6.3mm_D2.5mm_P7.62mm_Horizontal
R3: 100k; R_Axial_DIN0207_L6.3mm_D2.5mm_P7.62mm_Horizontal
U1: LM393; DIP-8_W7.62mm

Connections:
+5V: A1.27 (+5V), C1.1, R1.1, R4.1, U1.8 (V+)
/Geiger_pulse: R3.1, R5.2, U1.3 (+)
/Signal: A1.5 (D2), C2.2, R3.2, R4.2, U1.1
GND: A1.4 (GND), A1.29 (GND), C1.2, C2.1, J1.T, R2.2, U1.4 (V-)
unnamed: J1.S, R5.1
unnamed: R1.2, R2.1, U1.2 (-)

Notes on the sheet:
Entropy32 Recorder - By Alexander Higgins
Entropy32 Recorder
17/09/2026

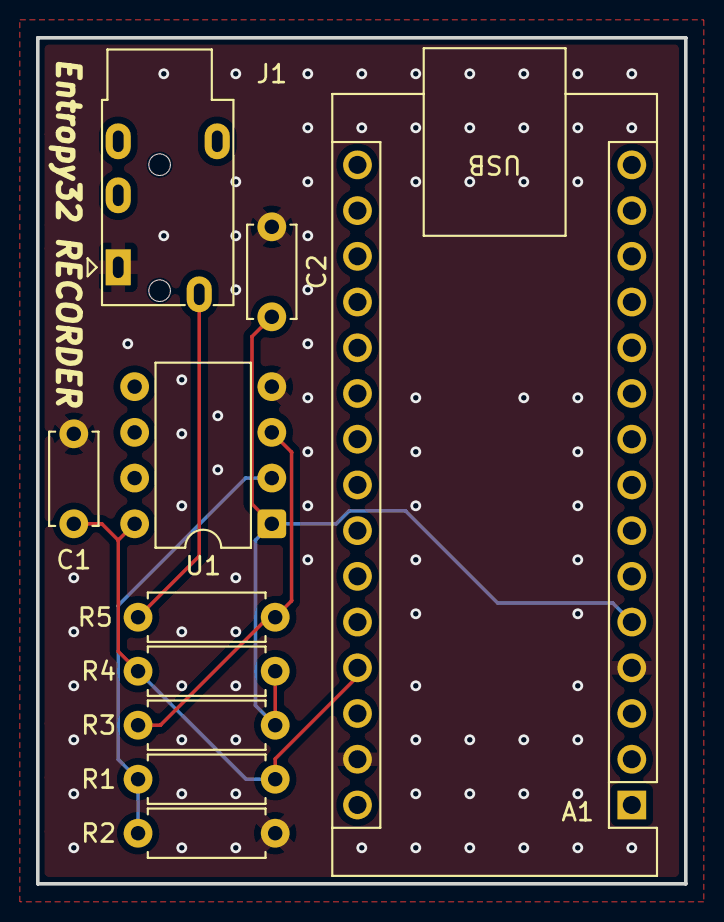
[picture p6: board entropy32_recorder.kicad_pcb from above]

Board: 2 copper layers, 36.0 x 47.0 mm, 10 parts (0 on the bottom side), 6 nets.

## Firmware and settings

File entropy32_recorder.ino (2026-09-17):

// Entropy32 Recorder — D2 raw edge capture
//
// Firmware for the standalone Entropy32 Recorder board (a separate board
// from Entropy32 / Entropy32 Plus). Does NOT run any filter, interval
// pairing, or SHA-256 conditioning — it only timestamps every rising edge
// on D2 (post-LM393) and streams it out over serial as CSV, for later
// statistical testing (e.g. NIST STS) of the raw entropy source.

#define D2_PIN 2
#define RING_SIZE 256   // must be a power of 2

volatile uint32_t timestamps[RING_SIZE];
volatile uint8_t head = 0;
volatile uint8_t tail = 0;
volatile bool overrun = false;

void onEdge() {
  uint8_t next_head = (uint8_t)(head + 1) & (RING_SIZE - 1);
  if (next_head == tail) {
    overrun = true;          // ring buffer full — an edge was dropped
    return;
  }
  timestamps[head] = micros();
  head = next_head;
}

uint32_t printed_index = 0;

void setup() {
  Serial.begin(115200);
  pinMode(D2_PIN, INPUT);    // board's existing pull-down handles bias
  attachInterrupt(digitalPinToInterrupt(D2_PIN), onEdge, RISING);
  Serial.println(F("edge_index,timestamp_us"));
}

void loop() {
  while (tail != head) {
    uint32_t ts = timestamps[tail];
    tail = (uint8_t)(tail + 1) & (RING_SIZE - 1);
    Serial.print(printed_index);
    Serial.print(',');
    Serial.println(ts);
    printed_index++;
  }
  if (overrun) {
    Serial.println(F("OVERRUN_DETECTED"));
    overrun = false;   // this run is invalid per the evidence protocol —
                        // note it and restart the capture
  }
}

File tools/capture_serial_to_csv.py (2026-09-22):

#!/usr/bin/env python3
"""
capture_serial_to_csv.py

Reads the D2 edge stream from the Entropy32 Recorder board (running
entropy32_recorder.ino) and writes it to a CSV file shaped like the
evidence protocol's raw/raw_edges.csv (edge_index, raw_timer_ticks,
monotonic_timestamp_us).

raw_timer_ticks is the board's micros() reading exactly as received
(wraps every ~4294967296us, ~71.58 minutes). monotonic_timestamp_us
is that value unwrapped into an ever-increasing 64-bit microsecond
count, reconstructed here by accumulating (raw[i] - raw[i-1]) mod 2**32
between consecutive edges. This is only valid as long as consecutive
edges are less than one full wrap period (~71.58 min) apart; a bigger
gap (e.g. the source is extremely sparse) would be indistinguishable
from a single wrap and silently understate elapsed time, so such gaps
are flagged rather than fixed up silently.

Every row is fsync'd to disk as soon as it's written — at this event
source's rate that's essentially free, and each edge is an
irreplaceable physical event, so there's nothing to configure and
nothing to report: a row on screen is already durable.

This script intentionally refuses to run at all if --out already has
data — one capture is one continuous, uninterrupted run from edge 0, per
the evidence protocol; there is no --resume. If the capture stops for
any reason, start a fresh run under a new --out filename.

On a fully complete run only (never on an interrupted or invalidated
one — see Drop detection below), a capture_status.json sibling is
written next to --out (e.g. raw_edges.csv -> raw_edges.status.json),
recording raw_edge_count, capture_start_utc/capture_end_utc, and the
zero overrun/drop counts implied by reaching that point at all. This is
the source for the evidence protocol's capture_status.json (Section 4).

Drop detection: the board tags every edge it sends with its own
sequential index (in addition to the timestamp). This script checks that
index against how many edges it has received so far; any mismatch means
a serial line was dropped, duplicated, or reordered in transit, and any
line that fails to parse at all means a line was garbled — either way,
per the evidence protocol's dropped-event criterion, that immediately
invalidates the capture. There is no soft "skip a few bad lines and
carry on": the run aborts on the first such event, because a garbled or
missing line is indistinguishable from a genuinely lost edge, and this
protocol does not interpolate.

Requires: pip install pyserial

Usage:
    python capture_serial_to_csv.py --port /dev/ttyUSB0 --count 2000
    python capture_serial_to_csv.py --port COM5 --count 2000
"""
import argparse
import csv
import json
import math
import os
import sys
from datetime import datetime, timedelta, timezone

import serial

from edge_timing import WRAP_WARN_MARGIN_US, wrap_delta, near_wrap


def format_duration(seconds):
    """Compact human-readable duration, e.g. '3h 22m' or '6w 2d' — scales
    from seconds up to weeks since a full campaign can run ~6 weeks."""
    seconds = int(round(seconds))
    if seconds < 60:
        return f"{seconds}s"
    minutes, seconds = divmod(seconds, 60)
    if minutes < 60:
        return f"{minutes}m {seconds}s"
    hours, minutes = divmod(minutes, 60)
    if hours < 24:
        return f"{hours}h {minutes}m"
    days, hours = divmod(hours, 24)
    if days < 7:
        return f"{days}d {hours}h"
    weeks, days = divmod(days, 7)
    return f"{weeks}w {days}d"


# Once we've heard from the board at least once, a read timeout just means
# the source hasn't fired yet (event rates are naturally variable) — not a
# wiring problem. Only nag about that once we've gone this many consecutive
# timeouts (~10 minutes) without hearing anything at all from the board.
IDLE_HEARTBEAT_TIMEOUTS = 60

# Thresholds (ms) used for the live Poisson-consistency check. Kept small —
# bounce/chatter shows up as an excess of very short inter-arrival times, and
# checking only the low end keeps the live status line to one line.
POISSON_CHECK_THRESHOLDS_MS = (1, 5, 10)


def status_path(out_path):
    """capture_status.json sits next to --out, named from it — e.g.
    raw_edges.csv -> raw_edges.status.json — so a package-assembly step
    can find and rename it into the protocol's capture_status.json."""
    root, _ext = os.path.splitext(out_path)
    return root + ".status.json"


def poisson_status(mean_us, diff_count, bounce_counts):
    """One-line verdict on whether short inter-arrival times (< 10ms) are
    consistent with a Poisson process, or flag likely comparator bounce.

    Takes running totals rather than the raw inter-arrival list so this
    can be called every edge (real captures run to >=1,000,000 edges,
    per the evidence protocol's SP 800-90B sample requirement) without
    rescanning history each time — see bounce_counts in main()."""
    if diff_count < 10:
        return "n/a (too few samples yet)"
    if mean_us <= 0:
        return "n/a"
    for t_ms in POISSON_CHECK_THRESHOLDS_MS:
        t_us = t_ms * 1000
        n_obs = bounce_counts[t_ms]
        n_exp = (1 - math.exp(-t_us / mean_us)) * diff_count
        if n_exp >= 3 and n_obs / n_exp > 2.0:
            return "WARNING: excess short (<10ms) intervals — check comparator bounce"
    return "ok"
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

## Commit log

2026-09-17 Initial commit: Entropy32 Recorder firmware, hardware, and tooling
    Adds the D2 edge-capture pilot sketch, serial-to-CSV capture tool,
    KiCad hardware design, and licensing.
    [arduino-nano.step, bom.csv, designators.csv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]
2026-09-17 Add rendering of device to readme
2026-09-17 Clarify Entropy32 Recorder is a standalone board, not Entropy32/Plus
    Fix docs and firmware comments that implied this board shares firmware
    with (or is a mode of) Entropy32/Entropy32 Plus. It's a separate board
    that only captures raw, unconditioned entropy source data for
    statistical testing, before that source is trusted for use in
    Entropy32 Plus's seed generation. Also drops a stale gitignore
    exception left over from an old project name.
    [capture_serial_to_csv.py, entropy32_recorder.ino]
2026-09-18 Fix timer-wrap bug in capture tooling, add live QA feedback
    The 32-bit micros() timer wraps every ~71.58 min but neither the
    firmware nor capture_serial_to_csv.py accounted for it, so
    monotonic_timestamp_us was just a copy of the wrapping raw value.
    This was silently corrupting real captures (confirmed in a 2000-edge
    pilot run, which wrapped mid-capture).
    - capture_serial_to_csv.py now reconstructs a true unwrapped
    monotonic_timestamp_us from raw_timer_ticks, warns on ambiguous
    multi-wrap gaps, and reports skipped/malformed serial lines.
    - Add tools/check_edges.py: a pre-flight sanity check (monotonicity,
    contiguity, and an inter-arrival-vs-Poisson comparison to catch
    LM393 comparat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
    [capture_serial_to_csv.py, check_edges.py]
2026-09-18 Add SP 800-90B evidence protocol and derivation tooling
    Adds entropy32_evidence_protocol.md defining the raw/derived evidence
    package for validating the Geiger entropy source, plus
    tools/derive_evidence.py to reconstruct Entropy32's exact 200us
    filter/pairing/bit-extraction semantics from a capture and produce a
    NIST non-IID-ready comparison_bits.bin.
    Hardens capture_serial_to_csv.py per the protocol: refuses to
    resume/overwrite an existing capture without confirmation, validates
    edge_index sequencing and rejects garbled lines as invalid captures
    rather than skipping them, and fsyncs to disk (configurable via
    --flush-every) so no captured edge is lost short of power failure.
    Timer-wrap math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
    [capture_serial_to_csv.py, derive_evidence.py, edge_timing.py]
2026-09-18 Add 10,000-edge pilot capture and its derived evidence/NIST results
    First end-to-end smoke test of the capture -> derive -> ea_non_iid
    pipeline: tools/raw_edges.csv (10,000 D2 edges), the protocol's
    derived/ package computed from it, and the resulting non-IID test
    output (H_original = 0.667787 bits/bit, min-entropy per the Collision
    estimator).
    Well below the protocol's 1,000,000-comparison-bit stop gate (Section
    3), so this is not a valid SP 800-90B evidence run -- it confirms the
    tooling works correctly ahead of a full-length capture.
    [all_intervals_us.csv, firmware_accepted_intervals_us.csv, raw_edges.csv]
2026-09-19 Close provenance and loss-accounting gaps in the evidence pipeline
    Adds firmware provenance tracking, capture-completion records, and a
    full evidence-package assembler, closing the gaps between what
    entropy32_evidence_protocol.md's package layout (Section 4/10) calls
    for and what the tooling actually produced:
    - derive_evidence.py: --source-dir auto-fills derivation_report.json's
    source_repo/source_commit/entropy32_firmware_blob_sha from a local
    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
2026-09-22 Package the second capture as an immutable evidence directory, retire loose scratch files
    Runs a fresh 10,000-edge capture through the full pipeline and commits
    the result as entropy32_sp80090b_2026-09-22a/ (manifest.json,
    capture_status.json, SHA256SUMS, raw/derived/nist) via
    package_evidence.py, instead of leaving loose files under tools/.
    The old pilot's tools/raw_edges.csv and tools/derived/ were tracked at
    fixed paths, so this capture would have silently overwritten their
    committed content in place -- exactly what entropy32_evidence_protocol.md
    Section 4 says never to do to a closed capture. Untracks those paths
    (and the transient tools/nist_std*.txt/raw_edges.status.json files that
    fe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
    [all_intervals_us.csv, firmware_accepted_intervals_us.csv, raw_edges.csv]
2026-10-05 Add dead-time calibration to check_edges.py's Poisson comparison
    Non-paralyzable detector dead time (e.g. the tube/comparator pulse
    width measured on a scope) means a detected inter-arrival time is
    tau + Exponential(true_rate), not a plain exponential from zero. A
    naive Poisson comparison always reads as a deficit of short gaps near
    tau, even on a healthy source. --dead-time-ns folds tau into the
    expectation so only genuine bounce/chatter gets flagged.
